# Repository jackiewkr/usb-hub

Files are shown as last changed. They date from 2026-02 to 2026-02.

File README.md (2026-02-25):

# 5.25" drive bay USB hub

## Why?
My PC case lacks front IO, due to it being from the early 90s. As such, all the USB headers
are located at the back of the motherboard. The pin headers for front IO on my motherboard
are unused, so this project should rectify that.

## What?
The aim is to create a 4-port USB hub, able to be mounted within a 5.25" PC drive bay.
More (semi-)detailed specifications below:
- Have 4 downstream USB 2.0 high-speed capable ports
- Be powered by standard Molex connector (aka 4-pin peripheral power connectors)
- Include current sensing on a port-by-port basis (don't kill all ports if only one overcurrents)
- Need no configuration from the user (work automatically once connected)
- Not to kill my motherboard or power supply

## Current Status
- Schematic designed fully [done]
- Initial PCB layout designed [working]
- First boards manufactured & tested [not yet]
- Revised boards [not yet]
- Outer case designed & printed [not yet]

## Schematic Details
The design is based of the Microchip USB2504, a 4-port USB 2.0 hub controller IC. 
The schematic largely follows the design of the evaluation board schematic, with
changes to limit certain functionality (no LEDs, EVB uses ganged current sensing, etc.)

Note that this schematic uses the TPS2560 for current sensing. The OUT1, OUT2 pins
are mis-assigned in the KiCad library as Output instead of Power Output. Please ignore
any errors generated in the DRC due to this.

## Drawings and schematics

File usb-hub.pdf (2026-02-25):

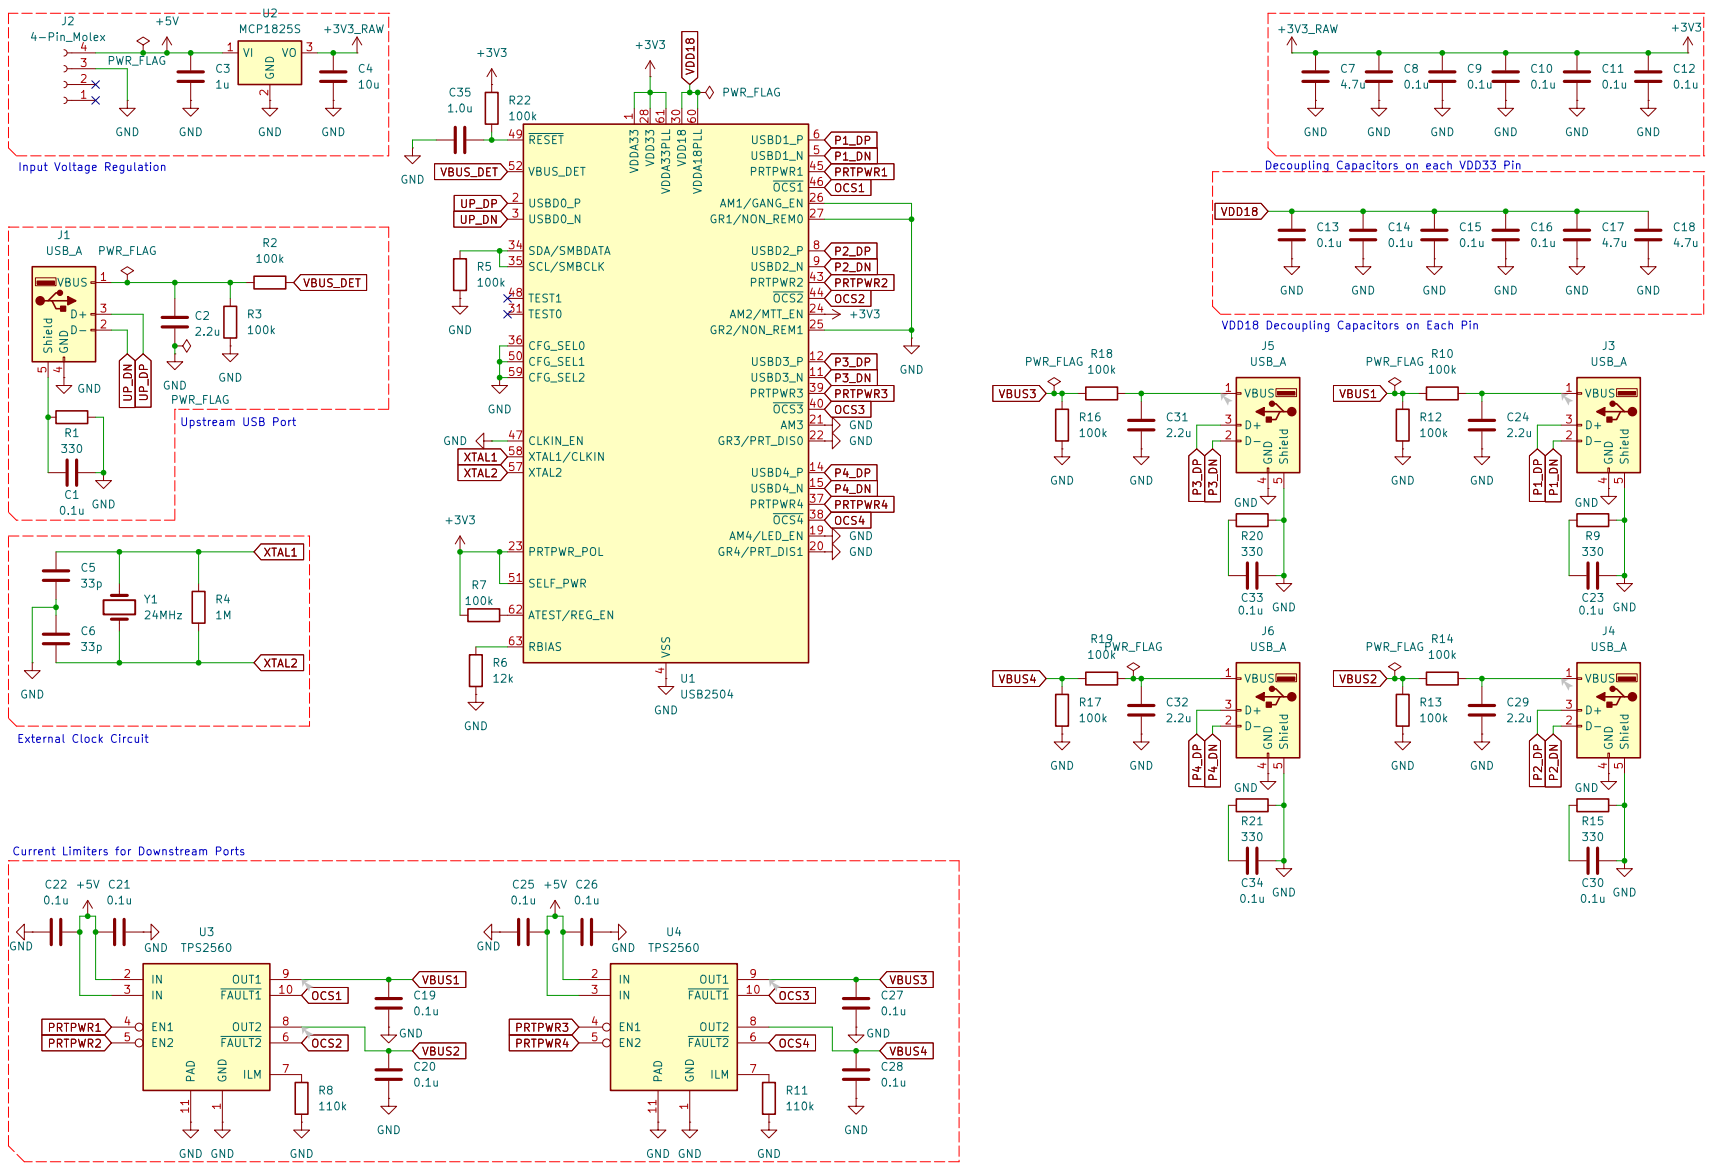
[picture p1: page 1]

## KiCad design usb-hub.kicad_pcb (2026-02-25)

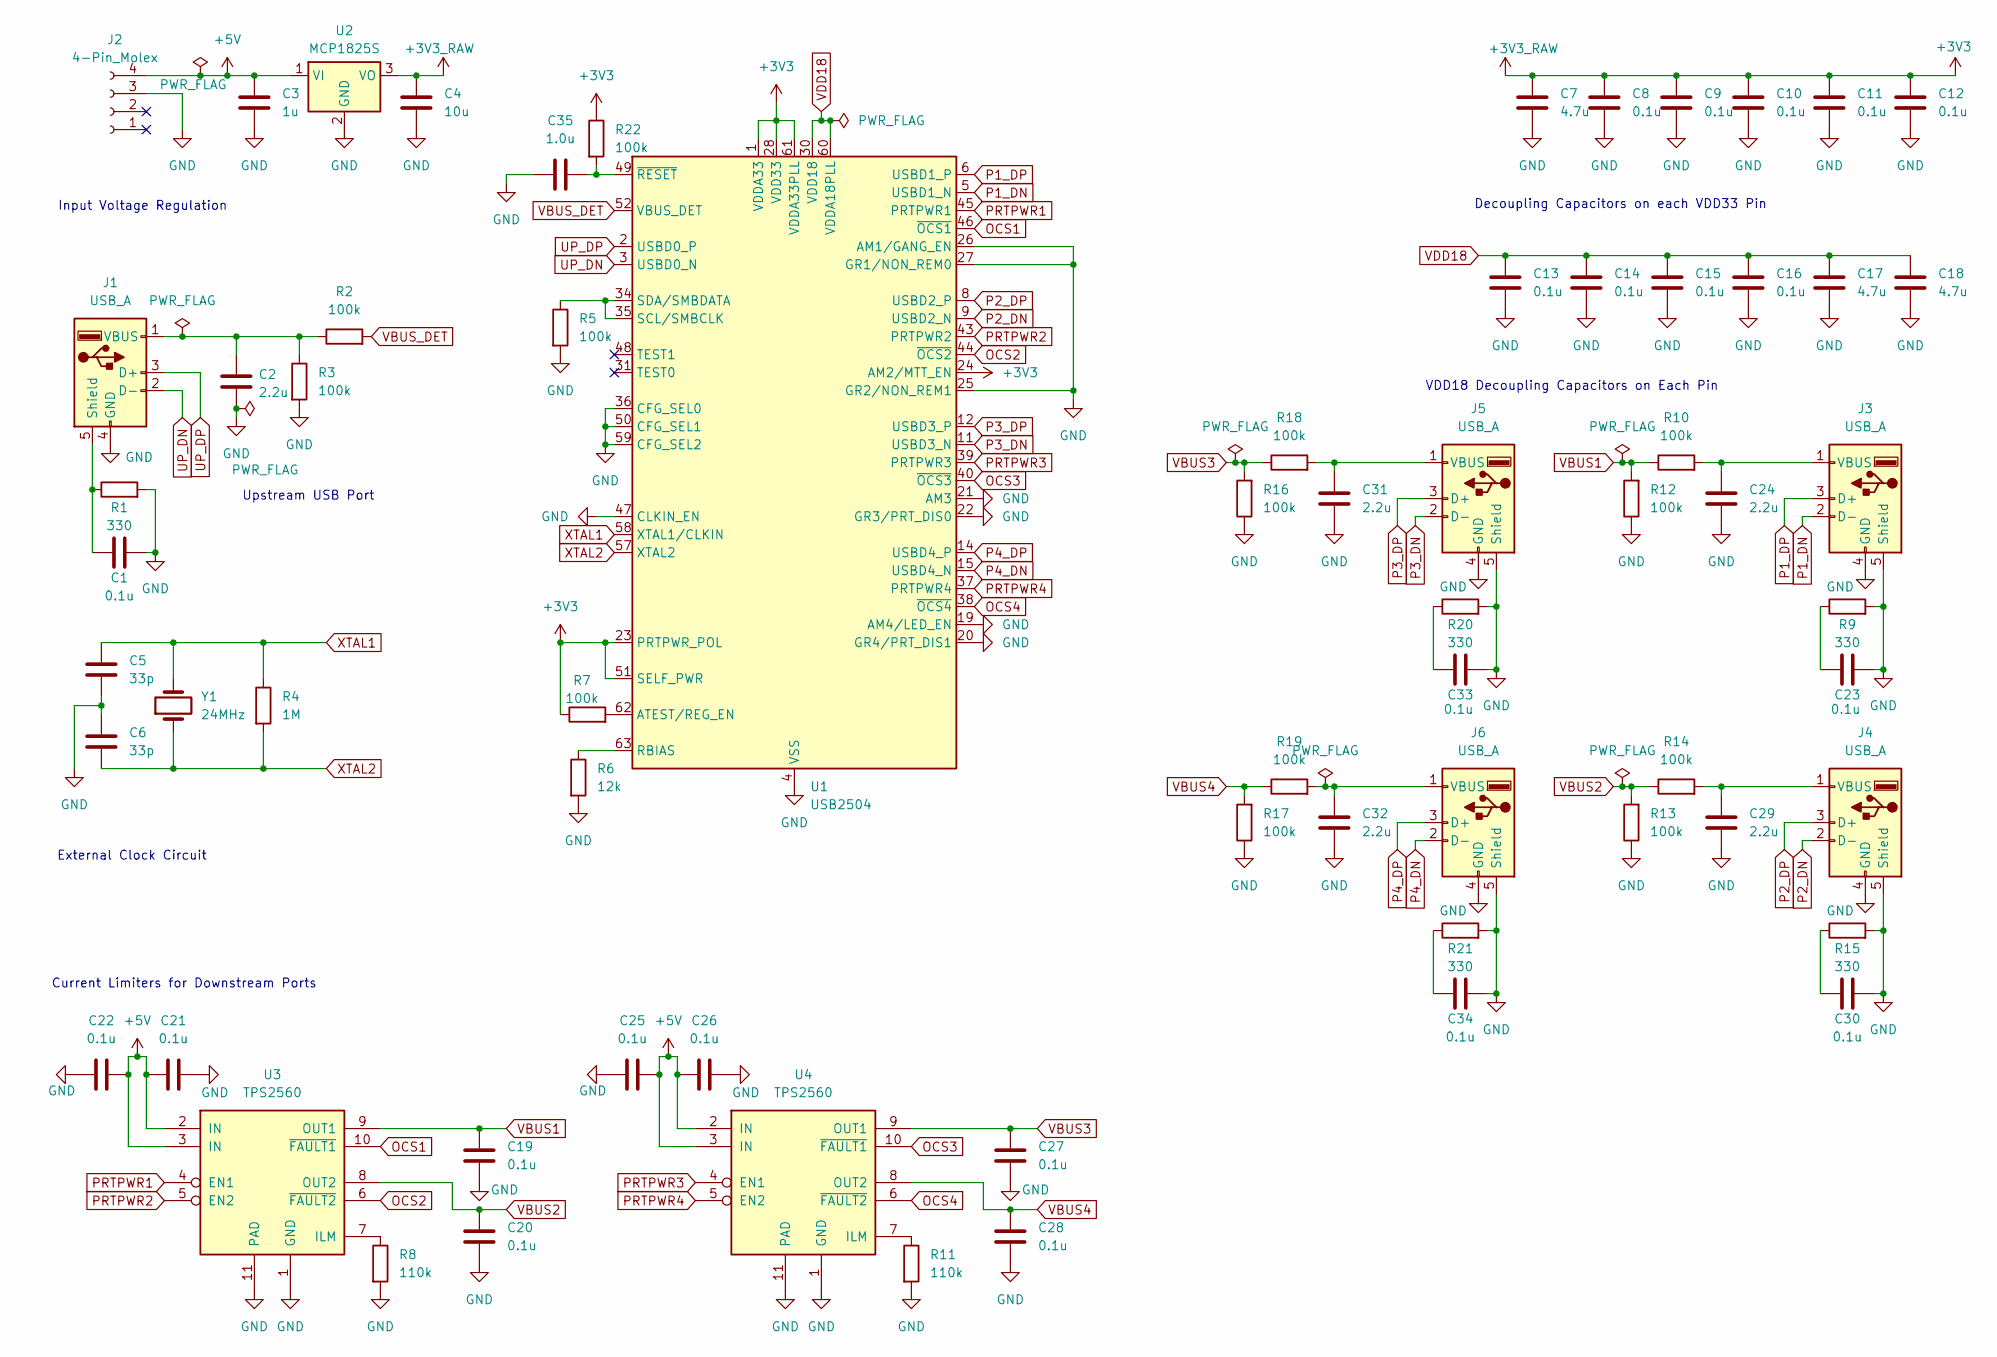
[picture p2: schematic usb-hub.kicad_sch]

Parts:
C1, C8, C9, C10, C11, C12, C13, C14, C15, C16, C19, C20, C21, C22, C23, C25, C26, C27, C28, C30, C33, C34: 0.1u; R_0805_2012Metric_Pad1.20x1.40mm_HandSolder
C2, C24, C29, C31, C32: 2.2u; R_0805_2012Metric_Pad1.20x1.40mm_HandSolder
C3: 1u; R_0805_2012Metric_Pad1.20x1.40mm_HandSolder
C4: 10u; R_0805_2012Metric_Pad1.20x1.40mm_HandSolder
C5, C6: 33p; R_0805_2012Metric_Pad1.20x1.40mm_HandSolder
C7, C17, C18: 4.7u; R_0805_2012Metric_Pad1.20x1.40mm_HandSolder
C35: 1.0u; R_0805_2012Metric_Pad1.20x1.40mm_HandSolder
J1, J3, J4, J5, J6: USB_A; USB_A_Receptacle_GCT_USB1046
J2: 4-Pin_Molex; SolderWire-1sqmm_1x04_P5.4mm_D1.4mm_OD2.7mm
R1, R9, R15, R20, R21: 330; R_0805_2012Metric_Pad1.20x1.40mm_HandSolder
R2, R3, R5, R7, R10, R12, R13, R14, R16, R17, R18, R19, R22: 100k; R_0805_2012Metric_Pad1.20x1.40mm_HandSolder
R4: 1M; R_0805_2012Metric_Pad1.20x1.40mm_HandSolder
R6: 12k; R_0805_2012Metric_Pad1.20x1.40mm_HandSolder
R8, R11: 110k; R_0805_2012Metric_Pad1.20x1.40mm_HandSolder
U1: USB2504; LQFP-64_10x10mm_P0.5mm
U2: MCP1825S; SOT-223
U3, U4: TPS2560; VSON-10-1EP_3x3mm_P0.5mm_EP1.65x2.4mm_ThermalVias
Y1: 24MHz; Crystal_SMD_2016-4Pin_2.0x1.6mm

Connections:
+3V3: C4.1, C7.1, C8.1, C9.1, C10.1, C11.1, C12.1, R7.1, R22.1, U1.1 (VDDA33), U1.7 (VDDA33), U1.13 (VDDA33), U1.23 (PRTPWR_POL), U1.24 (AM2/MTT_EN), U1.28 (VDD33), U1.51 (SELF_PWR), U1.61 (VDDA33PLL), U2.3 (VO)
+5V: C3.1, C21.1, C22.2, C25.2, C26.1, J2.4, U2.1 (VI), U3.2 (IN), U3.3 (IN), U4.2 (IN), U4.3 (IN)
GND: C1.2, C2.1, C3.2, C4.2, C5.2, C6.1, C7.2, C8.2, C9.2, C10.2, C11.2, C12.2, C13.2, C14.2, C15.2, C16.2, C17.2, C18.2, C19.2, C20.2, C21.2, C22.1, C23.2, C24.2, C25.1, C26.2, C27.2, C28.2, C29.2, C30.2, C31.2, C32.2, C33.2, C34.2, C35.1, J1.4 (GND), J2.3, J3.4 (GND), J3.5 (Shield), J4.4 (GND), J4.5 (Shield), J5.4 (GND), J5.5 (Shield), J6.4 (GND), J6.5 (Shield), R1.2, R3.2, R5.2, R6.2, R8.2, R9.2, R11.2, R12.1, R13.1, R15.2, R16.1, R17.1, R20.2, R21.2, U1.4 (VSS), U1.10 (VSS), U1.16 (VSS), U1.19 (AM4/LED_EN), U1.20 (GR4/PRT_DIS1), U1.21 (AM3), U1.22 (GR3/PRT_DIS0), U1.25 (GR2/NON_REM1), U1.26 (AM1/GANG_EN), U1.27 (GR1/NON_REM0), U1.29 (VSS), U1.36 (CFG_SEL0), U1.41 (VSS), U1.47 (CLKIN_EN), U1.50 (CFG_SEL1), U1.53 (VSS), U1.55 (VSS), U1.59 (CFG_SEL2), U1.64 (VSS), U2.2 (GND), U3.1 (GND), U3.11 (PAD), U4.1 (GND), U4.11 (PAD)
unnamed: C23.1, R9.1
unnamed: C30.1, R15.1
unnamed: C33.1, R20.1
unnamed: C34.1, R21.1
unnamed: C1.1, J1.5 (Shield), R1.1
unnamed: C2.2, J1.1 (VBUS), R2.1, R3.1
unnamed: C24.1, J3.1 (VBUS), R10.2
unnamed: C29.1, J4.1 (VBUS), R14.2
unnamed: C31.1, J5.1 (VBUS), R18.2
unnamed: C32.1, J6.1 (VBUS), R19.2
unnamed: R7.2, U1.62 (ATEST/REG_EN)
unnamed: R6.1, U1.63 (RBIAS)
unnamed: R5.1, U1.34 (SDA/SMBDATA), U1.35 (SCL/SMBCLK)
unnamed: C35.2, R22.2, U1.49 (~RESET)
unnamed: R8.1, U3.7 (ILM)
unnamed: R11.1, U4.7 (ILM)
OCS1: U1.46 (~OCS1), U3.10 (~FAULT1)
OCS2: U1.44 (~OCS2), U3.6 (~FAULT2)
OCS3: U1.40 (~OCS3), U4.10 (~FAULT1)
OCS4: U1.38 (~OCS4), U4.6 (~FAULT2)
P1_DN: J3.2 (D-), U1.5 (USBD1_N)
P1_DP: J3.3 (D+), U1.6 (USBD1_P)
P2_DN: J4.2 (D-), U1.9 (USBD2_N)
P2_DP: J4.3 (D+), U1.8 (USBD2_P)
P3_DN: J5.2 (D-), U1.11 (USBD3_N)
P3_DP: J5.3 (D+), U1.12 (USBD3_P)
P4_DN: J6.2 (D-), U1.15 (USBD4_N)
P4_DP: J6.3 (D+), U1.14 (USBD4_P)
PRTPWR1: U1.45 (PRTPWR1), U3.4 (EN1)
PRTPWR2: U1.43 (PRTPWR2), U3.5 (EN2)
PRTPWR3: U1.39 (PRTPWR3), U4.4 (EN1)
PRTPWR4: U1.37 (PRTPWR4), U4.5 (EN2)
UP_DN: J1.2 (D-), U1.3 (USBD0_N)
UP_DP: J1.3 (D+), U1.2 (USBD0_P)
VBUS1: C19.1, R10.1, R12.2, U3.9 (OUT1)
VBUS2: C20.1, R13.2, R14.1, U3.8 (OUT2)
VBUS3: C27.1, R16.2, R18.1, U4.9 (OUT1)
VBUS4: C28.1, R17.2, R19.1, U4.8 (OUT2)
VBUS_DET: R2.2, U1.52 (VBUS_DET)
VDD18: C13.1, C14.1, C15.1, C16.1, C17.1, C18.1, U1.30 (VDD18), U1.42 (VDD18), U1.54 (VDD18), U1.60 (VDDA18PLL)
XTAL1: C5.1, R4.1, U1.58 (XTAL1/CLKIN), Y1.2
XTAL2: C6.2, R4.2, U1.57 (XTAL2), Y1.1

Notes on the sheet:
Input Voltage Regulation
Decoupling Capacitors on each VDD33 Pin
Upstream USB Port
External Clock Circuit
Current Limiters for Downstream Ports
VDD18 Decoupling Capacitors on Each Pin

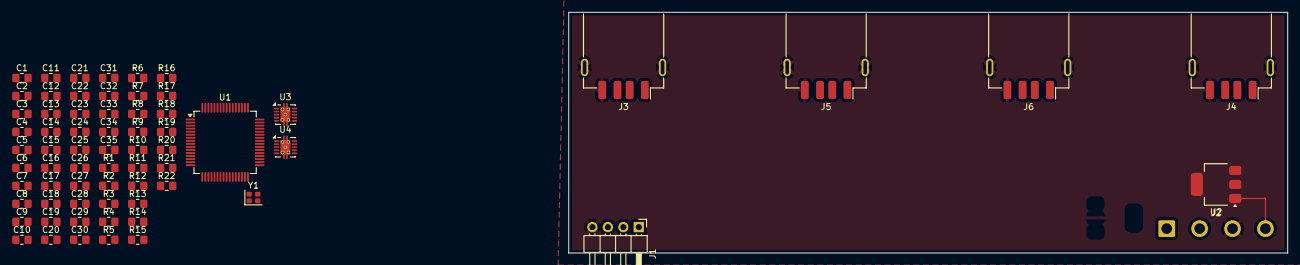
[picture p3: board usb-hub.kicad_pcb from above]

Board: 2 copper layers, 118.0 x 39.5 mm, 68 parts (0 on the bottom side), 45 nets.

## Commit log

2026-02-25 Added initial schematic design
    Initial schematic design and basic positioning of USB headers on PCB board.
    [usb-hub.kicad_pcb, usb-hub.kicad_sch]
2026-02-25 Added schematic printout
